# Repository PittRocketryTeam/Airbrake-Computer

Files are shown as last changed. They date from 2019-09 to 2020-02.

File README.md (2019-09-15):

# Airbrake-Computer
Code for the dedicated airbrake computer on the vehicle

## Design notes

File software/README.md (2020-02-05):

# Airbrake (VDS) Software
## 1. Overview

This software was designed to run on a Teensy 3.6 in support of the 2019-2020 Pitt SOAR variable drag system (VDS) airbrake for the full scale NASA USLI launch vehicle. The purpose of the airbrake is to control the launch vehicle's apogee to try to get the vehicle as close to its declared target apogee as possible.

It consists of a finite state machine driven by a deployment algorithm consisting of a number of parameters. 'Parameters’ are aspects of the model which can be independently modified to alter the performance of what is called the 'main algorithm', which is the program flow for the main function. 

Integer parameters are static values whereas sub-algorithms are pieces of functionality. The division of the main algorithm into sub-algorithm is to enable ease of testing and to identify independent functionality which can be reused elsewhere on the vehicle. Sub-algorithms which are more difficult to test feature simpler implementations to make testing and verification easier. 

The primary design goals of this software (aside from supporting the mission of the airbrake) are: 

1. __Fail safely.__ Under no circumstances should the airbrake's operation lead to the failure of a launch. This means all operations err on the side of doing nothing (e.g. the system never detects launch where the was no launch event, but it ight fail to detect a launch where there was a launch event).

2. __Make testing easy.__ Due to the aforementioned safety-critical nature of airbrake software, all software has been designed in discrete units that are easily testable. Interfaces were written with testing in mind.

3. __Promote code reuse.__ This is just one of several software projects for Pitt SOAR's 2019-2020 USLI vehicle, and several other software projects use similar functionality. Heavy emphasis was placed on reusing software from other projects and on making new software reusable elsewhere.

Beyond design goals, success is defined as the launch vehicle achieving within 70 feet of its target apogee, regardless of whether or not the airbrake blades ever deploy during flight. Shown below is a formalize definition of how success is defined for airbrake operation.

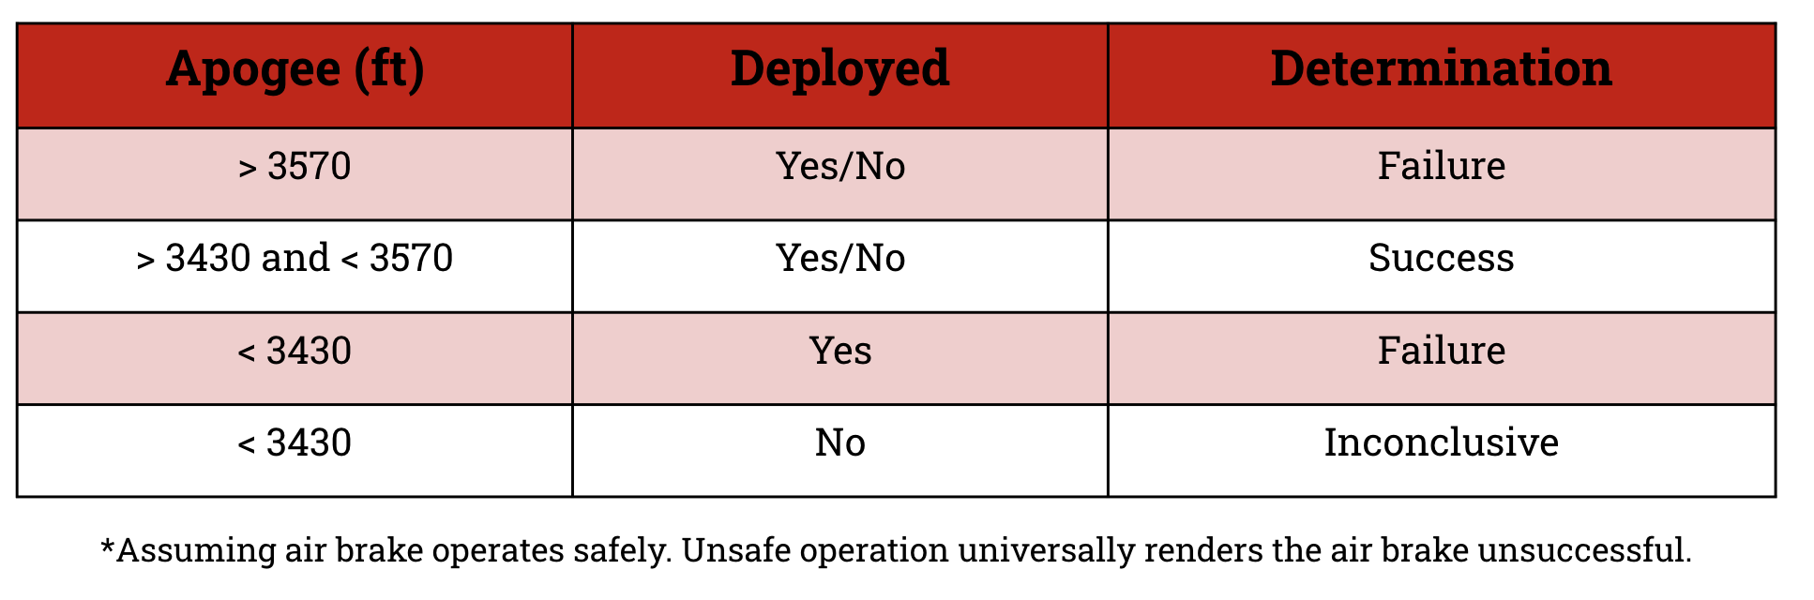
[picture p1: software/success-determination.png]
success-determination


## 2. Sub-Algorithm Descriptions

### 2.1 SA-1: Determination of Launch Detection

TODO: Add description

### 2.2: SA-2 Determination of Motor Burnout

TODO: Add description

### 2.3: SA-3: Airbrake Deployment Incrementation Algorithm

TODO: Add description

### 2.4: SA-4: Apogee Prediction

#### 2.4.1. General Approach

This algorithm accepts data points (time in seconds and altitude in feet) collected since motor burnout was detected. It uses the least-squares method to fit a second degree polynomial to the data points, which it uses to generate a three coefficients. It then determines the maximum of this second degree polynomial, which it returns as the predicted apogee. 

#### 2.4.2. Assumptions

* This algorithm assumes that launch and motor burnout have already been detected.

* This algorithm assumes that sufficient data has been collected since motor burnout to make a reasonable estimate (this is accomplished in the data acquision threshold check (daqThresholdMet()). 

TODO: Add description

### 2.5: SA-5: Determination of Descent Detection

TODO: Add description

## 3. Project Structure

* `src` - source files
* `include` - header files
* `lib` - external libraries
* `test` - unit tests
* `data` - data files to supply mocked sensors with data

## 4. Collaboration Process

In order to maintain records of which code has been flown, whenever a version is flown, it will be tagged as a major release.

As far as collaboration, discretion should be used when pushing to the master branch. No code which does not compile should be pushed to master (and ideally, code that does not work should not be pushed to master either, but this is harder to verify). When deciding whether or not to push directly to master, use your best judgement. If you made a small change (e.g. edited a comment or a README), it's probably okay to push to master. On the other hand, if you've been editing a major file (e.g. main.cpp, LaunchVehicle.cpp, or Airbrake.cpp especially), you should probably ask the airbrake-software channel in the team Slack before pushing changes to master, mostly because there will likely be heavy merge conflicts.

If you plan to make major changes to a major file, create your own branch and create a pull reqest containing a description of what you've changed (focus on change in functionality) and assign Rachel Misbin as the assignee. 

Commit messages should be descriptive, more so when important changes were made. 

## 5. Build Configurations

In order to fly and test the same code, there are several flags that are set to modify the behavior of the code. Below, the different build configurations for flight and test are explained. 

### 5.1. Flight Build

The flight build (what flies on the full scale vehicle) should have the following flags set:

| Flag | Value | Explanation |
|:---:|:---:|:---:|
| VERBOSE | false | Limit I/O to allocate more resources towards computation |
| MANUAL_MODE | false | Disable manual intervention and mock sensors |

All flight builds must uncomment the line `build_flags = -Wall -Wextra -Werror`.

### 5.2. Test Build

The test build (what's used during testing and __SHOULD NOT BE FLOWN__ can have the `VERBOSE` and `MANUAL_MODE` flags set to whatever is desirable for testing. Note that `MANUAL_MODE = true` enables the mock sensors.

## 6. Basic Style Guidelines

For the sake of consistency, this repo uses the following coding standards: 

* Brackets should be on their own lines, and ALL conditional statements and loops must have brackets, like this: 

```c++
if(initAlt == -1) 
{
    Serial.println("Cannot poll altitude --- ground pressure not yet set!");
}
else
{
    data.altimeterData.altitude = bmp.readAltitude(initAlt);
}
```

* Each function's definition belongs in a header file and should have a block comment with Javadoc-style annotations, like this:

```c++
/******************************************************************************************
 * Initialize vehicle and sensors. Accepts an IMU and Altimeter objects so these sensors
 * can be mocked.
 * 
 * @param AbstractImu imu object (or mock)
 * @param AbstractAltimeter altimeter object (or mock)
 *****************************************************************************************/
void init(AbstractImu* i, AbstractAltimeter* a);
```

* Any constants (aside from -1, 0, and 1) should be named and should feature a block comment with a description of the constant, its intended use, and its imperial units (if relevant), like this:

```c++
/**************************************************************************************************
 * I-2: Range for incremental partial deployments (tolerance around target apogee).     Unit: feet
 * 
 * This is used to control what the system considers apogee. Apogee, to the system, is 
 * TARGET_APOGEE +/- PARTIAL_DEPLOYMENT_RANGE, e.g. if target apogee is 3700 feet, the system 
 * considers anything between 3695 and 3905 to be apogee.
 *************************************************************************************************/
#define PARTIAL_DEPLOYMENT_RANGE 5  
````

* Lines should not exceed 100 characters.

* All code should be compiled with all warnings enabled and reported as errors, using the compiler flags `-Wall -Wextra -Werror` (these are automatically included in the `platform.ini` file, which controls the build process. __These flags must be enabled for all flight builds.__

## 7. Dev Environment Setup

### 7.1. PlatformIO
All development used the PlatformIO extension for Visual Studio Code. Additionally, you need to download the [Teensyduino addon](https://www.pjrc.com/teensy/td_download.html) in order to upload to the Teensy. 

To build the project, run `pio run`. To upload the project to a Teensy board, run `platformio run --target upload`. To view serial output, run `platformio device monitor`.

### 7.2. Test Environment Setup
1. Make sure `MANUAL_MODE` is set to true.
2. Make sure you have a micro SD card with the data file specified by `LOGFILE` on the teensy.
3. Make sure the micro SD is in the teensy.

## 8. Relevant Links

* [Original deployment algorithm documentation](https://docs.google.com/document/d/1qq0nmyqW3g3wkucI6V3XiiaBdJnb-GQawClglQOAYOM/edit#)
* [Sub-algorithm test plan](https://docs.google.com/document/d/130fPIKDiWxRjwC1eHgn8vEJmvnMhvv1aIwvGFC2JZu0/edit)
* [Sub-algorithm test matrix](https://docs.google.com/spreadsheets/d/1-hUiYAFvpETWn4wtxwzF-okXmnx6dhZY2qigwSgHFRo/edit)

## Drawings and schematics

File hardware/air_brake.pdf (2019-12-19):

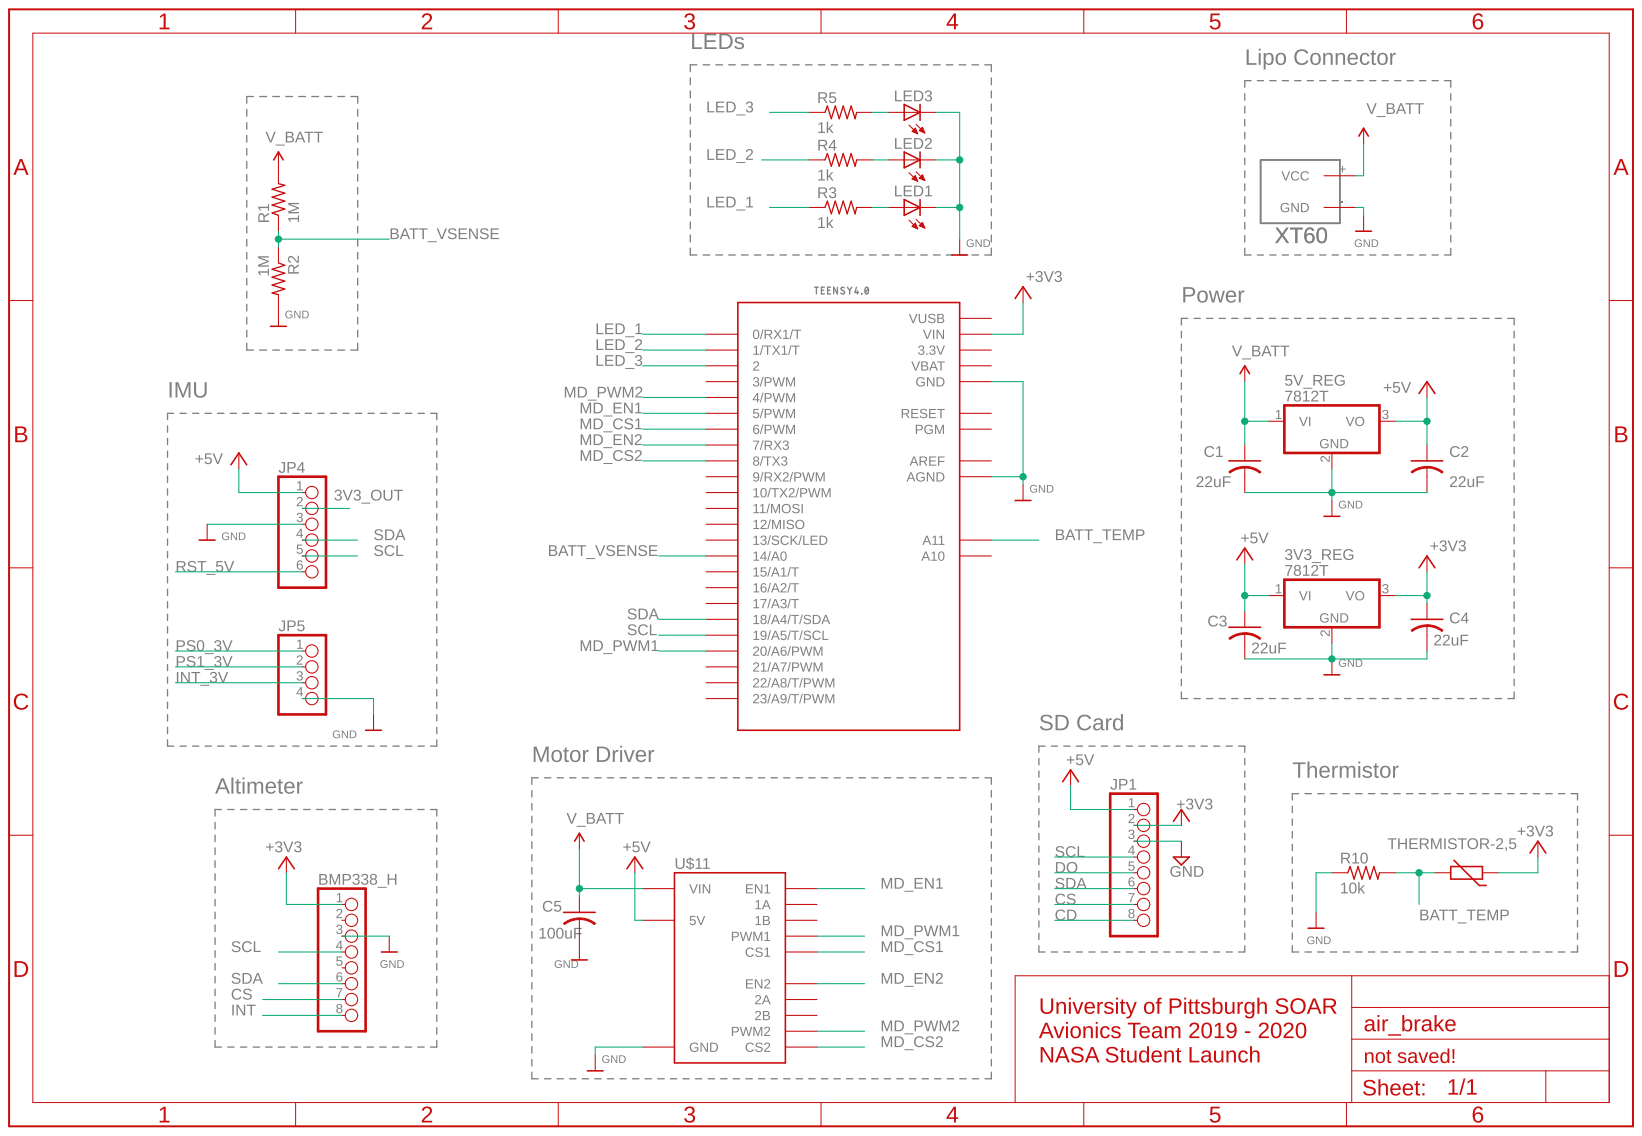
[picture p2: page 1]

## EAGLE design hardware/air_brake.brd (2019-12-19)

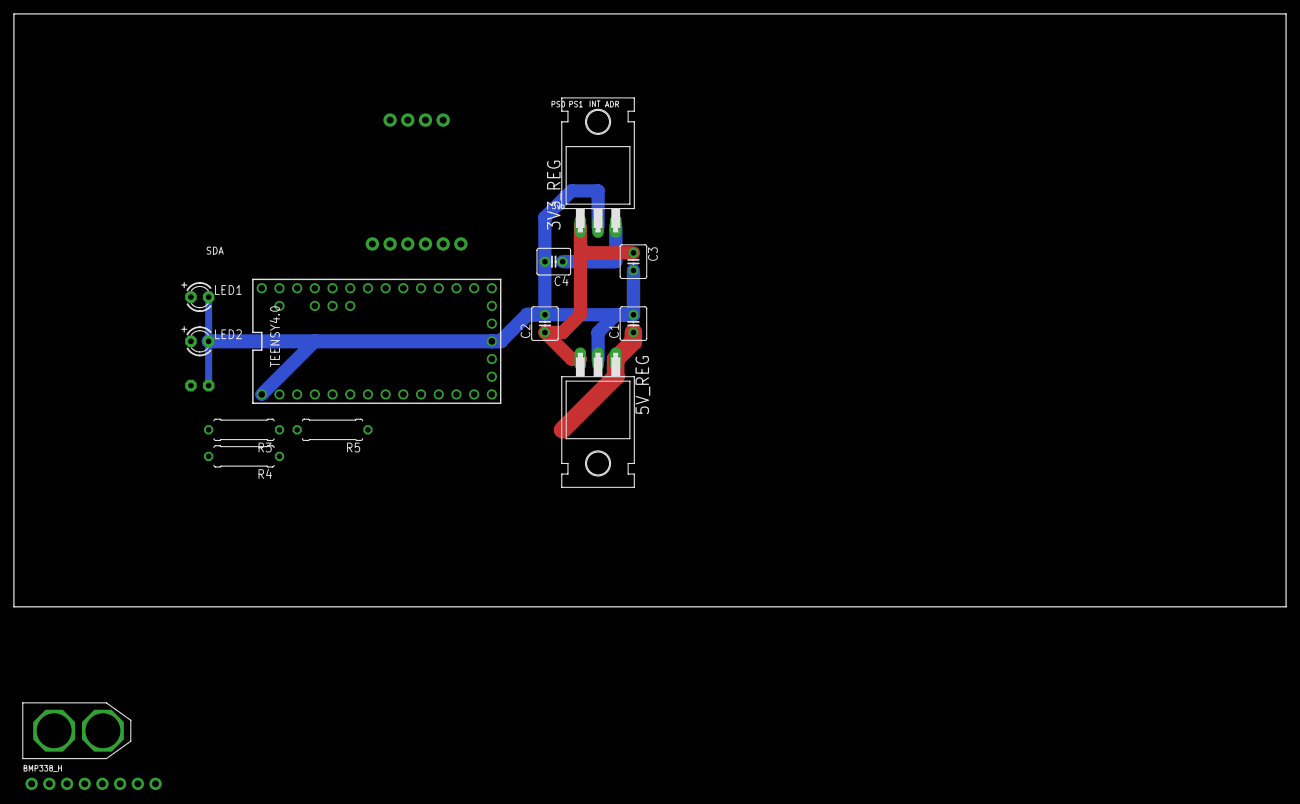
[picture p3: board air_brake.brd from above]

Board: 2 copper layers, 182.6 x 85.1 mm, 17 parts (1 on the bottom side), 13 nets.

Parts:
3V3_REG, 5V_REG: 7812T; TO220H
BMP338_H: 1X08_ROUND_70
C1, C2, C3, C4: 22uF; C025-040X050
JP4: 1X06_ROUND_76
JP5: 1X04_ROUND_76
LED1, LED2, LED3: LED3MM
R3, R4, R5: 1k; 0309/10
TEENSY4.0: TEENSY_3.0_ALL_PINS; TEENSY_3.0-3.2&LC_ALL_PINS
U$1: XT60

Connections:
3.3V: TEENSY4.0.3.3V, TEENSY4.0.3.3V1
+3V3: 3V3_REG.3, BMP338_H.1, C4.1, TEENSY4.0.VIN
+5V: 3V3_REG.1, 5V_REG.3, C2.1, C3.1, JP4.1
GND: 3V3_REG.2, 5V_REG.2, BMP338_H.3, C1.2, C2.2, C3.2, C4.2, JP4.3, JP5.4, LED1.K, LED2.K, LED3.K, TEENSY4.0.AGND, TEENSY4.0.GND, TEENSY4.0.GND1, U$1.-
LED_1: R3.1, TEENSY4.0.0
LED_2: R4.1, TEENSY4.0.1
LED_3: R5.1, TEENSY4.0.2
unnamed: LED1.A, R3.2
unnamed: LED2.A, R4.2
unnamed: LED3.A, R5.2
SCL: BMP338_H.4, JP4.5, TEENSY4.0.19/A5
SDA: BMP338_H.6, JP4.4, TEENSY4.0.18/A4
V_BATT: 5V_REG.1, C1.1, U$1.+

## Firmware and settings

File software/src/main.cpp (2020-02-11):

#include <Arduino.h>

#include "Airbrake_State.hpp"
#include "LaunchVehicle.hpp"
#include "Airbrake.hpp"
#include "SdFat.h"
#include "MockHelper.hpp"

/*********************************************** Functions ***************************************/
bool manualSkipState(void);
void setup(void);
void loop(void);
/*************************************************************************************************/

/************************************************ Globals ****************************************/
LaunchVehicle vehicle;  // Makes decisions about the state of the vehicle based on sensor data
Airbrake airbrake;      // Actuates the air brake and interacts with air brake hardware
Airbrake_State state;   // Keeps track of current state in FSM
/*************************************************************************************************/

/**************************************************************************************************
 * One-time setup
 *************************************************************************************************/
void setup() 
{
    delay(4000);
    if (VERBOSE) { Serial.println("In setup"); }

    state = START;

    vehicle.init(MANUAL_MODE); 

    airbrake.init();
}
/**************************************************************************************************
 * State machine loop
 *************************************************************************************************/
void loop() 
{
    delay(STATE_DELAY);
    
    switch (state)
    {
        case START:

            if (VERBOSE) { Serial.println("State: START"); }

            if (vehicle.launchDetected())       // Check if launch has been detected 
            {
                state = LAUNCH_DETECTED;
            }

            break;
        
        case LAUNCH_DETECTED:

            if (VERBOSE) { Serial.println("State: LAUNCH_DETECTED"); }

            if (vehicle.motorBurnoutDetected()) // Check if motor burnout has been detected
            {
                state = BURNOUT_DETECTED;
            }

            break;

        case BURNOUT_DETECTED:

            if (VERBOSE) { Serial.println("State: BURNOUT_DETECTED"); }

            if (vehicle.daqThresholdMet())     // Check if data acquisition threshold has been met
            {
                state = DAQ_THRESHOLD_MET_ACTIVE_ADJUST;
            }

            break;
        
        case DAQ_THRESHOLD_MET_ACTIVE_ADJUST:

            if (VERBOSE) { Serial.println("State: DAQ_THRESHOLD_MET_ACTIVE_ADJUST"); } 

            if (vehicle.descentDetected()) // Check for descent
            {
                state = DESCENT_DETECTED;
                break;
            }

            if (vehicle.isWithinImmediateDeploymentRange() > 0) // Check for immediate deployment
            {
                airbrake.deployCompletely();  // Deploy air brake completely
                while (!vehicle.descentDetected())
                {   
                    // Wait until descent is detected
                } 
                state = DESCENT_DETECTED;     // Switch to descent detected state
                break;
            }

            // Otherwise, proceed with fine adjustment algorithm
            if (vehicle.isWithinPartialDeploymentRange() > 0) // Check if predicted apogee > target apogee
            {
                int percent_deployment = vehicle.calculatePercentDeployment(); // Calculate action
                airbrake.setAbsoluteDeployment(percent_deployment);            // Deploy percent air brake 
                break;
            }

            break;

        case DESCENT_DETECTED:

            if (VERBOSE) { Serial.println("State: DESCENT_DETECTED"); }

            airbrake.retractCompletely(); // Retract to 0%
            state = TERMINATION;          // Terminate

            break;

        case TERMINATION:

            if (VERBOSE) { Serial.println("State: TERMINATION"); }
            
            while (true)
            {
                // Infinite loop (state machine termination)
            } 

            break;

        default:

            state = DESCENT_DETECTED; // Should never be here. Retract to 0% and terminate

            break;
    }
}
/**************************************************************************************************
 * Handles option to skip states in manual mode
 *************************************************************************************************/
bool manualSkipState()
{
    bool ret = false;
    if (MANUAL_MODE)
    {
        Serial.println("Enter 'c' to skip state or 'w' to wait");
        while (Serial.available() == 0) 
        { 
            // Wait for serial
        }
        ret = (Serial.read() == 'c');
    }

    return ret;
}

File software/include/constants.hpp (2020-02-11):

#ifdef FLIGHT_BUILD // constants for flight build

    #define STEPS_FOR_100_PERCENT 200
    #define RPM 120
    #define MICROSTEPS 1

    #define LOGFILE (char*)""
    #define VERBOSE false        // Disable verbosity
    #define MANUAL_MODE false    // Use real sensors

    /***************************************************************************************************
     * I-1: Target apogee.                                                                  Unit: meters
     **************************************************************************************************/
    #define TARGET_APOGEE 1066.8

    /**************************************************************************************************
     * I-2: Range for incremental partial deployments (tolerance around target apogee).     Unit: meters
     * 
     * This is used to control what the system considers apogee. Apogee, to the system, is 
     * TARGET_APOGEE +/- PARTIAL_DEPLOYMENT_RANGE, e.g. if target apogee is 3700 feet, the system 
     * considers anything between 3695 and 3905 to be apogee.
     *************************************************************************************************/
    #define PARTIAL_DEPLOYMENT_RANGE 1.524

    /**************************************************************************************************
     * I-3: Range for immediate full deployment.                                            Unit: meters
     * 
     * This is used to control the range where the air brake will immediately deploy. For example, if
     * target apogee is 3700 feet, if the air brake system detects that it's between 3675 and 3725
     * feet, it will trigger immediate 100% deployment of the air brake.
     *************************************************************************************************/
    #define IMMEDIATE_DEPLOYMENT_RANGE 7.62

    /************************************************************************************************** 
     * I-5: Offset for altimeter reading to calibrate altimeter to match stratologger.      Unit: meters
     * 
     * This is used to account for the fact that NASA's altitude determination is made using the 
     * stratologger, not the air brake altimeter, so the air brake altimeter should be calibrated to
     * stratologger to ensure that it's trying to optimize the apogee reading that actually matters
     * for the competition.
     *************************************************************************************************/ 
    #define ALT_CALIBRATION_OFFSET 0.6096

    /************************************************************************************************** 
     * I-6: Data acquisition threshold (change in height since motor burnout).              Unit: meters
     * 
     * This is one of the parameters that is used to set the data acquisition threshold. It defines
     * the height since motor burnout detection when enough data has been collected. For example, if
     * this value is 50, that means at least 50 feet mush be gained over the altiude at which motor 
     * burnout was completed.
     *************************************************************************************************/ 
    #define DAQ_THRESHOLD_ALTITUDE 15.24

    /************************************************************************************************** 
     * I-7: Data acquisition threshold (# data points collected since motor burnout).       Unit: Unit
     * 
     * This is one of the parameters that is used to set the data acquisition threshold. It defines
     * the number of data points collected since motor burnout detection when enough data has been 
     * collected. For example, if this value is 50, that means at least 50 feet mush be gained over 
     * the altiude at which motor burnout was completed.
     *************************************************************************************************/ 
    #define DAQ_THRESHOLD_DATA_POINTS 55

    /**************************************************************************************************
     * Lower bound of partial deployment range.                                             Unit: meters
     *************************************************************************************************/
    #define PARTIAL_DEPLOYMENT_LOWER_BOUND (TARGET_APOGEE - PARTIAL_DEPLOYMENT_RANGE)

    /**************************************************************************************************
     * Upper bound of partial deployment range.                                             Unit: meters
     *************************************************************************************************/
    #define PARTIAL_DEPLOYMENT_UPPER_BOUND (TARGET_APOGEE + PARTIAL_DEPLOYMENT_RANGE)
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

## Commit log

2019-09-23 first shecmatic commit
    [air_brake.brd, air_brake.sch]
2019-09-23 updated cap values
    [air_brake.brd, air_brake.sch]
2019-09-25 very rough prelim board layout
    [air_brake.brd, air_brake.sch]
2019-10-03 began power routing
    [air_brake.brd]
2019-11-16 Create MP6500 Stepper Motor Driver Carrier.lbr
2019-11-29 updated to reflect no logging
    [air_brake.brd, air_brake.sch]
2019-12-02 Changes to Airbrake Sch.
    Add 5V and Motor
    [air_brake.sch]
2019-12-03 Added 5V Reg and stepper motor
    [air_brake.sch]
2019-12-19 Added IMU and altimeter code
2019-12-20 Created mock IMU class for testing
2019-12-20 Fixed mock sensor classes to read data from SD card
    [lessdata.csv]
2019-12-23 Added MockHelper and linter files
    [CPPLINT.cfg]
2019-12-28 Fixing mocked classes. added overarching abstract IMU and altimeter classes to make LaunchVehicle accept either mocked sensor classes or non-mocked sensor classes
    [LaunchVehicle.cpp]
2019-12-28 Now runs with MockHelper object; still need to figure out cause of serial monitor stalls (seems to be related to MockHelper)
    [MockHelper.cpp]
2020-01-07 Changed to Teensy 3.6
    [air_brake.sch]
2020-01-07 Added Buzzer
    [air_brake.sch]
2020-01-12 add stepper library
2020-01-16 fixing stepper library
2020-01-16 stepper library is fixed
2020-01-30 Small changes to sensor classes, closer to getting mockhelper working
2020-01-30 Moved verbose flag from board to constants
2020-01-31 uploaded datasets for testing
    [lessdata.csv, loggylog.csv]
2020-02-02 Added altimeter calibration offset to mock sensor and real sensor readings
2020-02-02 Added stepper driver init
2020-02-08 Added teensy time lib
2020-02-11 Moved altimeter/imu creation and initialization from main to LaunchVehicle

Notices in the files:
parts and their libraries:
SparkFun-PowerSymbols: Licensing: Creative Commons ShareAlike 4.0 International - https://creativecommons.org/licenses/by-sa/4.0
